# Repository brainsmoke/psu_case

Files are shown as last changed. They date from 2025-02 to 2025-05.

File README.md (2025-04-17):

# Front panel for MEAN WELL LRS-350-* PSUs

Printed 3mm thick in PETG to offset for material weaknesses due to print orientation.
100% infill (or enough wall thickness so that the slicer doesn't create a zig-zag pattern
for the walls).

TODO: coat it with a UV-blocking paint.

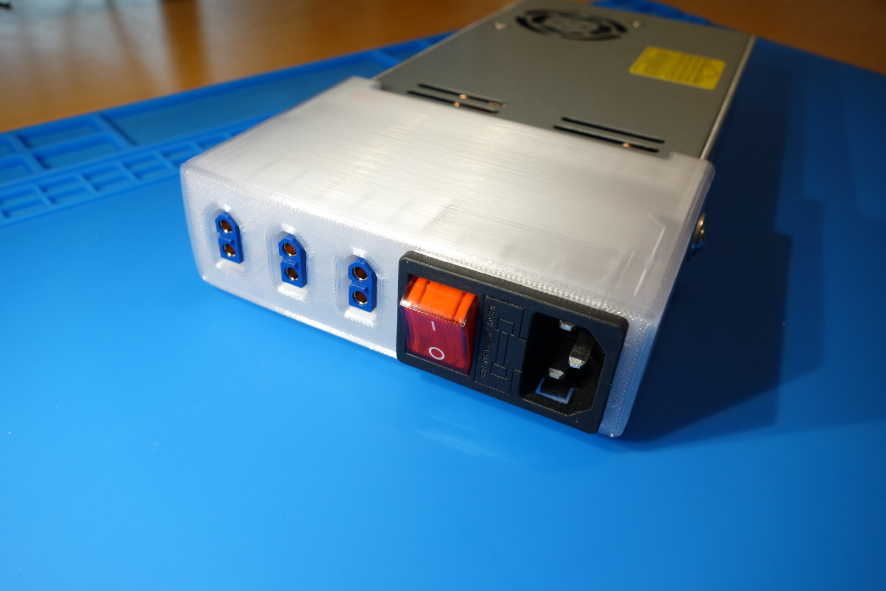
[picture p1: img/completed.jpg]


## prints:

* [Main case:](stl/cover.stl)
* [Shield for high voltage wires:](stl/power_shield.stl)

## PCB

* [XT60 'back plane':](pcb/gerb.zip)

## insides:

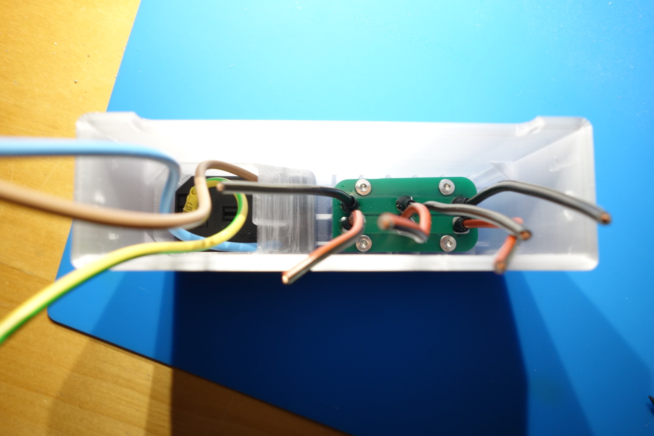
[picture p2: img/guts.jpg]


## type of C14 connector with rocker switch that fits the model:

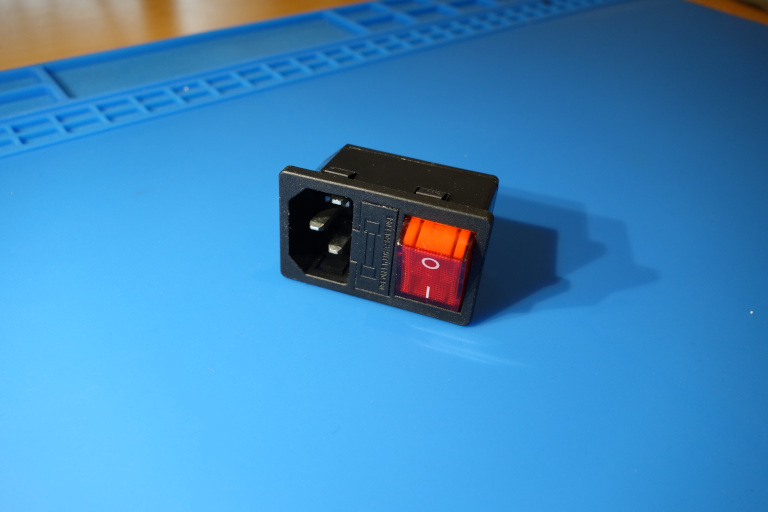
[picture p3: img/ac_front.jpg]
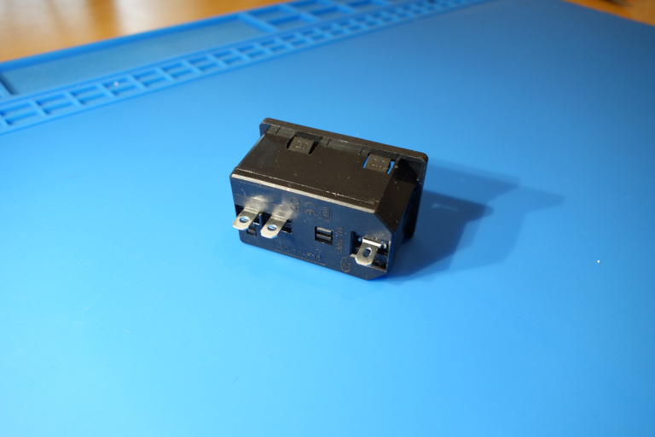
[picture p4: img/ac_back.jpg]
 

## Separator to shield input and output power, and neutral from live

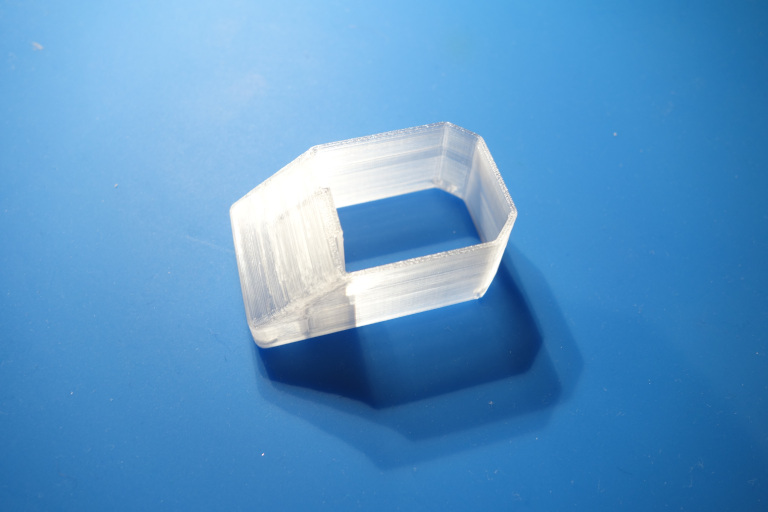
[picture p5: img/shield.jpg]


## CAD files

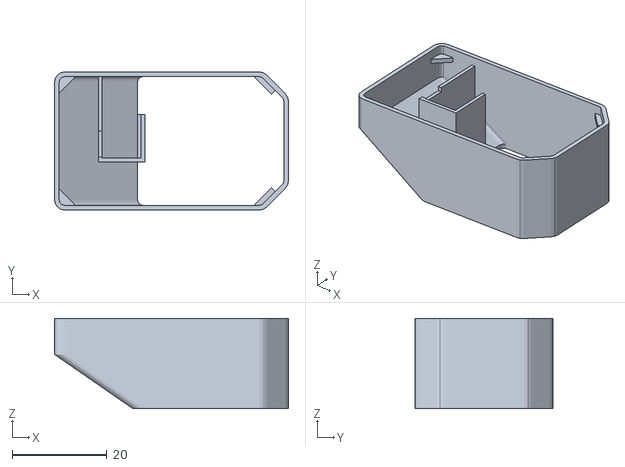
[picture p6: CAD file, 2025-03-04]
stl/power_shield.stl
49.3 x 29.1 x 19.0

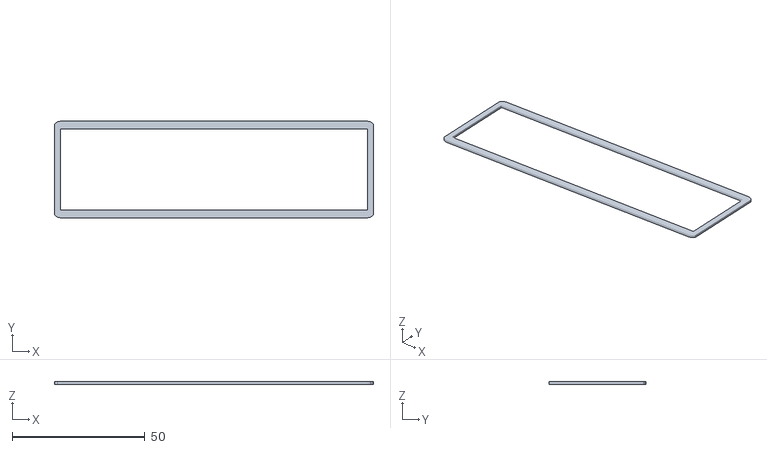
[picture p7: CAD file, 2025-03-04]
stl/cover_sleeve_test.stl
120.0 x 36.4 x 1.00

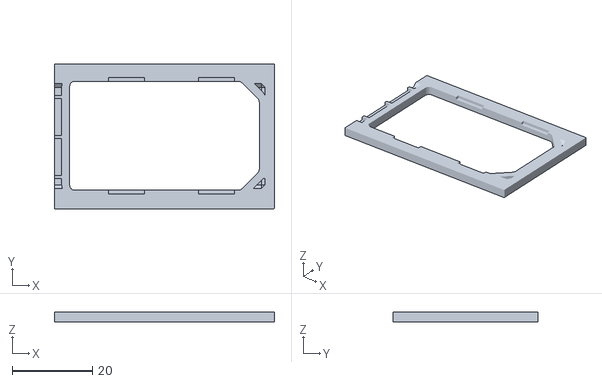
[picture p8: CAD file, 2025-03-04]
stl/cover_power_test.stl
55.0 x 36.2 x 2.40

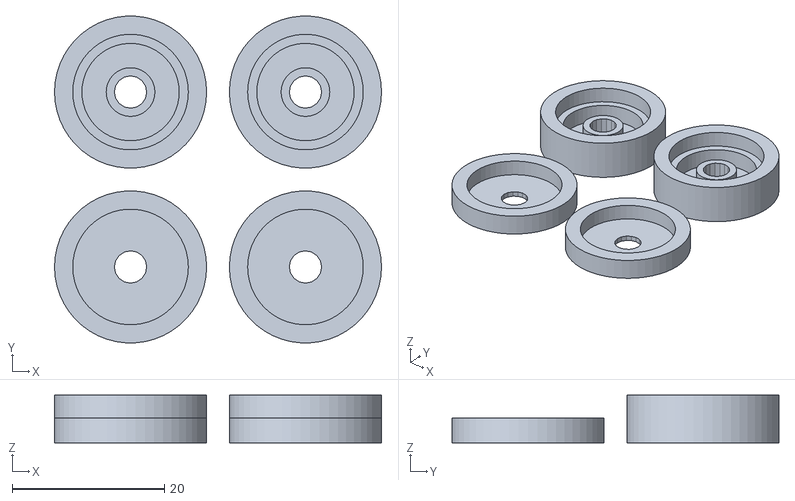
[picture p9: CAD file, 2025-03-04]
stl/feet.stl
43.0 x 43.0 x 6.30

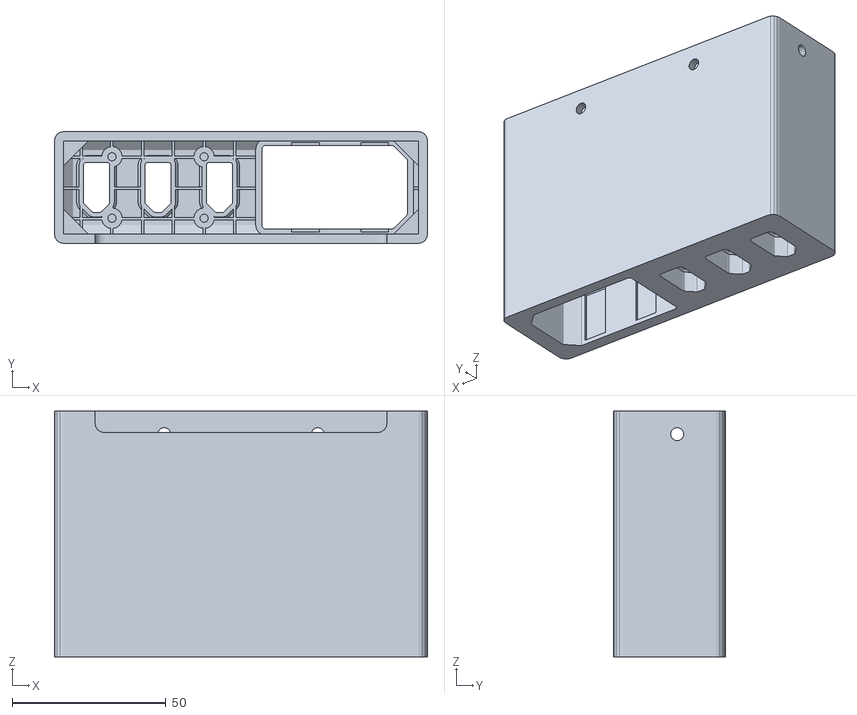
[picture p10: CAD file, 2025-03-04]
stl/cover.stl
121.4 x 36.4 x 80.0

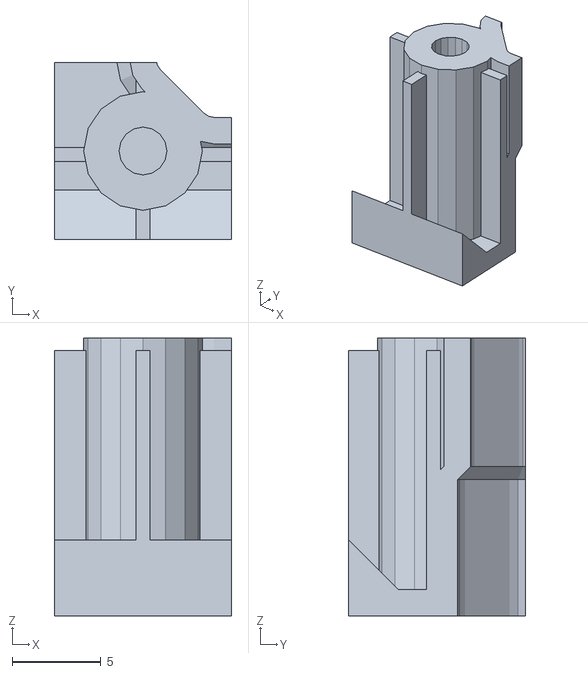
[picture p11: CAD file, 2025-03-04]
stl/cover_hole_test.stl
10.0 x 10.0 x 15.7

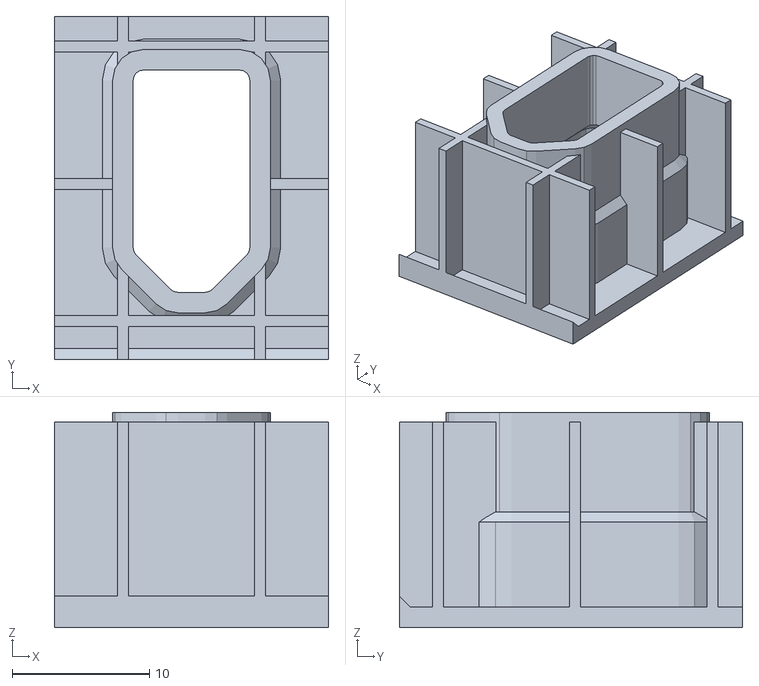
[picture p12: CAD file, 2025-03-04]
stl/xttest.stl
20.0 x 25.0 x 15.7

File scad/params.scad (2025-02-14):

depth=40;

xt60_loc = [ [-47,-depth, 15], [-27,-depth, 15], [-7,-depth, 15] ];
plug_loc = [5,-depth, 1.5];

margin = 0.2;

plug_margin=0.2;

xt60_margin = 0.25;
xt60m_margin = 1;

xt60_thickness = 1.5;
plug_thickness = 2;

case_w_inner = 115+2*margin;
case_h_inner = 30+2*margin;
case_thickness = 3;
case_front_thickness = 1.5;
case_w = case_w_inner + 2*case_thickness;
case_d = depth + 40;
case_h = case_h_inner + 2*case_thickness;

case_dim = [case_w, case_d, case_h];
case_dim_inner = [case_w_inner, case_d, case_h_inner];
case_dim_inside = [(case_w_inner+case_w)/2, case_d, (case_h_inner+case_h)/2];

bump_corner=(case_thickness+margin)*2.5;

front = [0,-1, 0];
bottom_front = [0,-1,-1];

grid_rows = 3;
grid_cols = 11;
grid_pitch = 10;
grid_thickness = .8;
grid_depth=12;
grid_xoff =-2;

screw_thread=3;
screw_hole_r=(screw_thread*.9)/2;
screw_hole_border=2;

mw_lrs_gap_d = 18.5;

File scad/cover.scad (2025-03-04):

use <utils.scad>
use <grid.scad>

use <mw_lrs.scad>
use <powerplug.scad>
use <power_shield.scad>
use <xt.scad>

include <params.scad>

$fn=16;
e=.001;

module cutout()
{
	mw_lrs_keepout(margin=margin);

	for ( p = xt60_loc )
	translate(p)
	translate([0,0,0])
	rotate([90,90,0])
	xt60f_cutout(margin=xt60_margin,m_margin=xt60m_margin,e=e);

	translate(plug_loc)
	{
	plug(margin=plug_margin, , extra_depth=-2);
	plug_latches_keepout(margin=plug_margin);
	}

	mw_lrs_holes()
	m4_hole(10, margin=.25);

	mw_lrs_vents_keepout(h=10, margin=1);
}

module shell()
{
	difference()
	{
		translate([0, -depth, -case_thickness-margin])
		rounded_block_y(case_dim, bottom_front, r=case_thickness);

		translate([0, -depth+case_front_thickness, -margin])
		chamfer_block([case_w_inner, case_d, case_h_inner], bottom_front, r=case_thickness);
	}
}

module round_corner(w)
{
	difference()
	{
		rotate([90,0,0])
		cylinder(w, r1=w, r2=0);
		union()
		{
			translate([-w-e,-w,-w])
			cube([w,w*2,w*2]);

			translate([-w,-w,-w-e])
			cube([w*2,w*2,w]);
		}
	}
}


module bump_corner(w)
{
	round_corner(w, $fn=4);
}

module front_grid()
{
	translate([0, -depth+e,-case_thickness/2])
	xz_toward_y()
	anchor(case_dim_inside, bottom_front)
	grid(case_dim_inside.x, case_dim_inside.z, case_thickness+grid_depth-e, grid_rows, grid_cols, pitch=grid_pitch, bar_width=grid_thickness, x_off=grid_xoff, y_off=0);
}

module at_panel_screws()
{
	for (x=[ -12, -42 ])
	for (z=[ 5, 25 ])
	translate([x,-depth, z])
	children();
}


module cover()
{
	difference()
	{
		union()
		{
			shell();
	
			intersection()
			{
				union()
				{
					front_grid();
					translate(plug_loc)
					plug(margin=plug_margin+plug_thickness, extra_depth=-2);
	
					for ( p = xt60_loc )
					translate(p)
					rotate([90,90,0])
					xt60f_shell_cutout(margin=  xt60_margin+xt60_thickness,
					                 m_margin=xt60m_margin+xt60_thickness);

					at_panel_screws()
					translate([0,-e, 0])
					xz_toward_y()
					linear_extrude(15.7+e)
					circle(screw_hole_r+screw_hole_border);

				}
				translate([0, -depth+e, case_h_inner/2])
				block(case_dim_inside, front);
			}

			translate([0,-margin,case_h_inner/2-margin])
			for (x=[1, -1])
			for (z=[1, -1])
			scale([x, 1, z])
			translate([-case_w_inner/2, 0,-case_h_inner/2])
			bump_corner(bump_corner);
		}
		union()
		{
			cutout();

			at_panel_screws()
			translate([0,case_thickness+e, 0])
			xz_toward_y()
			linear_extrude(15.7)
			circle(screw_hole_r);
		}
	}
}


module print_orientation()
{
	rotate([90,0,0])
	translate([0,depth,0])
	children();
}


print_orientation()
preview()
{
	mw_lrs();

	for ( p = xt60_loc )
	translate(p)
	rotate([90,90,0])
	xt60f();

	translate(plug_loc)
	plug();

	translate(plug_loc)
	power_shield();
}

print_orientation()
#cover();

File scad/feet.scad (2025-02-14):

include <params.scad>

use <mw_lrs.scad>

$fn=50;

feet_front_h = 3.3;
feet_back_h = feet_front_h + case_thickness;
indent_h = 2.5;
min_h=1.;
padd = 3;

feet_d=20;
feet_indent_d = 15.2;

border = 1.2;

pitch = feet_d+padd;

module foot(h, d, indent_h, indent_d, ring_h=0)
{
	b=1;
	difference()
	{
		cylinder(h=h, r=d/2);
		union()
		{
			translate([0,0,h+b])
			rotate([180,0,0])
			cylinder(h=b+indent_h, r=indent_d/2);

			translate([0,0,h])
			m4_hole(h+b, margin=.25);

			difference()
			{
				translate([0,0,h+b])
				rotate([180,0,0])
				cylinder(h=b+h-ring_h, r=indent_d/2-border);

				translate([0,0,-b])
				cylinder(h=2*b+h, r=4/2+border);
			}
		}
	}
}

for (x=[0,pitch])
{
	translate([x, 0, 0])
	foot(feet_front_h, feet_d, indent_h, feet_indent_d, min_h);

	translate([x, pitch, 0])
	foot(feet_back_h, feet_d, indent_h, feet_indent_d, min_h);
}

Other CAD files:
scad/mw_lrs.scad
scad/cover_hole_test.scad
scad/cover_power_test.scad
scad/cover_sleeve_test.scad
scad/grid.scad
scad/power_shield.scad
scad/powerplug.scad
scad/utils.scad
scad/xt.scad
scad/xttest.scad

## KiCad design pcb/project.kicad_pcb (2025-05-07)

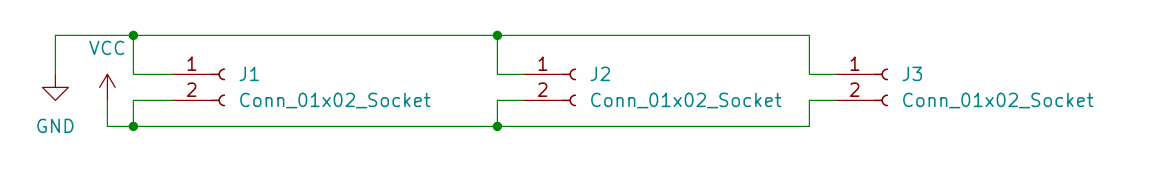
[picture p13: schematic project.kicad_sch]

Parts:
J1, J2, J3: Conn_01x02_Socket; AMASS_XT60-F_1x02_P7.20mm_Vertical

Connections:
GND: J1.1, J2.1, J3.1
VCC: J1.2, J2.2, J3.2

Board: 2 copper layers, 3 parts (0 on the bottom side), 2 nets, no tracks yet.

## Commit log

2025-01-29 untested, unfinished
    [cover.stl]
2025-01-31 chamfer xt60 holes
    [cover.scad, xt.scad, xttest.scad]
2025-01-31 add stls, unfinished, untested
    [cover.scad, cover.stl, xttest.stl]
2025-02-01 fix margin, add separate margin for xt60
    [cover.scad, cover.stl, xttest.stl]
2025-02-01 cleanup, add bumps
    [cover.scad]
2025-02-01 update stl, untested, unfinished
    [cover.stl]
2025-02-06 add tests, widen border
    [cover.scad, cover.stl, cover_power_test.scad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]
2025-02-07 save plastic, add tests
    [cover.scad, cover.stl, cover_hole_test.scad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]
2025-02-08 adjust power plug margin
    [cover.scad, cover.stl, cover_power_test.stl]
2025-02-11 add Makefile
    [cover.scad, power_shield.scad, powerplug.scad]
2025-02-11 adjust powerplug latch position
    [cover.stl, cover_hole_test.stl, cover_power_test.scad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]
2025-02-11 directory reorg
    [cover.scad, cover.stl, cover_hole_test.scad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]
2025-02-12 change shape of power plug latches to make it less removable from the inside
    [cover.scad, cover.stl, cover_power_test.stl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]
2025-02-12 add feet
    [cover.scad, cover.stl, feet.scad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]
2025-02-14 add separate parameter file
    [cover.scad, feet.scad, params.scad]
2025-02-14 add power shield image
2025-03-04 rotate models to print orientation
    [cover.scad, cover.stl, cover_hole_test.scad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]
2025-05-07 Use tighter tolerances on PCB for XT60 holes
    [project.kicad_pcb]
